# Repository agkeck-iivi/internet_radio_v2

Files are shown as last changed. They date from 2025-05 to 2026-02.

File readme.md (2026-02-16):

# Internet radio v2

## hardware

* ESP32s3 DevkitC N16R8
* ES8388 audio board
  * both clock and data lines require low pass filters with caps close to es8388
* 2 rotary encoders with push buttons and hardware debounce
  * encoder 1: volume + mute + hold down at boot to enter provisioning mode
  * encoder 2: station selection + display ip address + reboot

* 1 IR LED
* 1 OLED display spi interface

### prototype

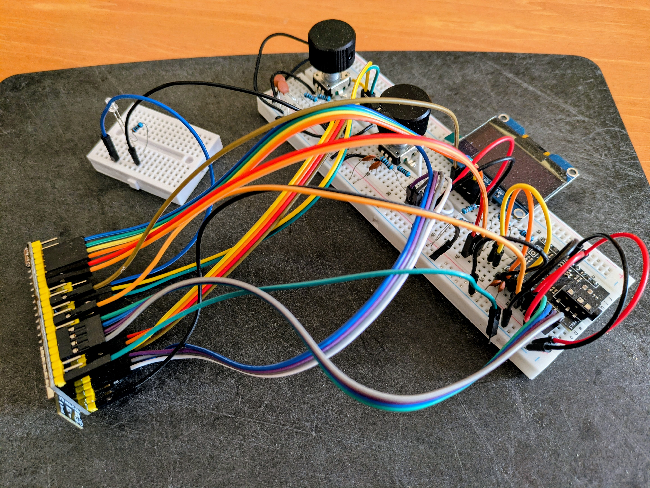
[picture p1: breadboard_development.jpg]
breadboard development

*Breadboard development*

### header wiring

header wiring
*Header wiring diagram*

### schematic

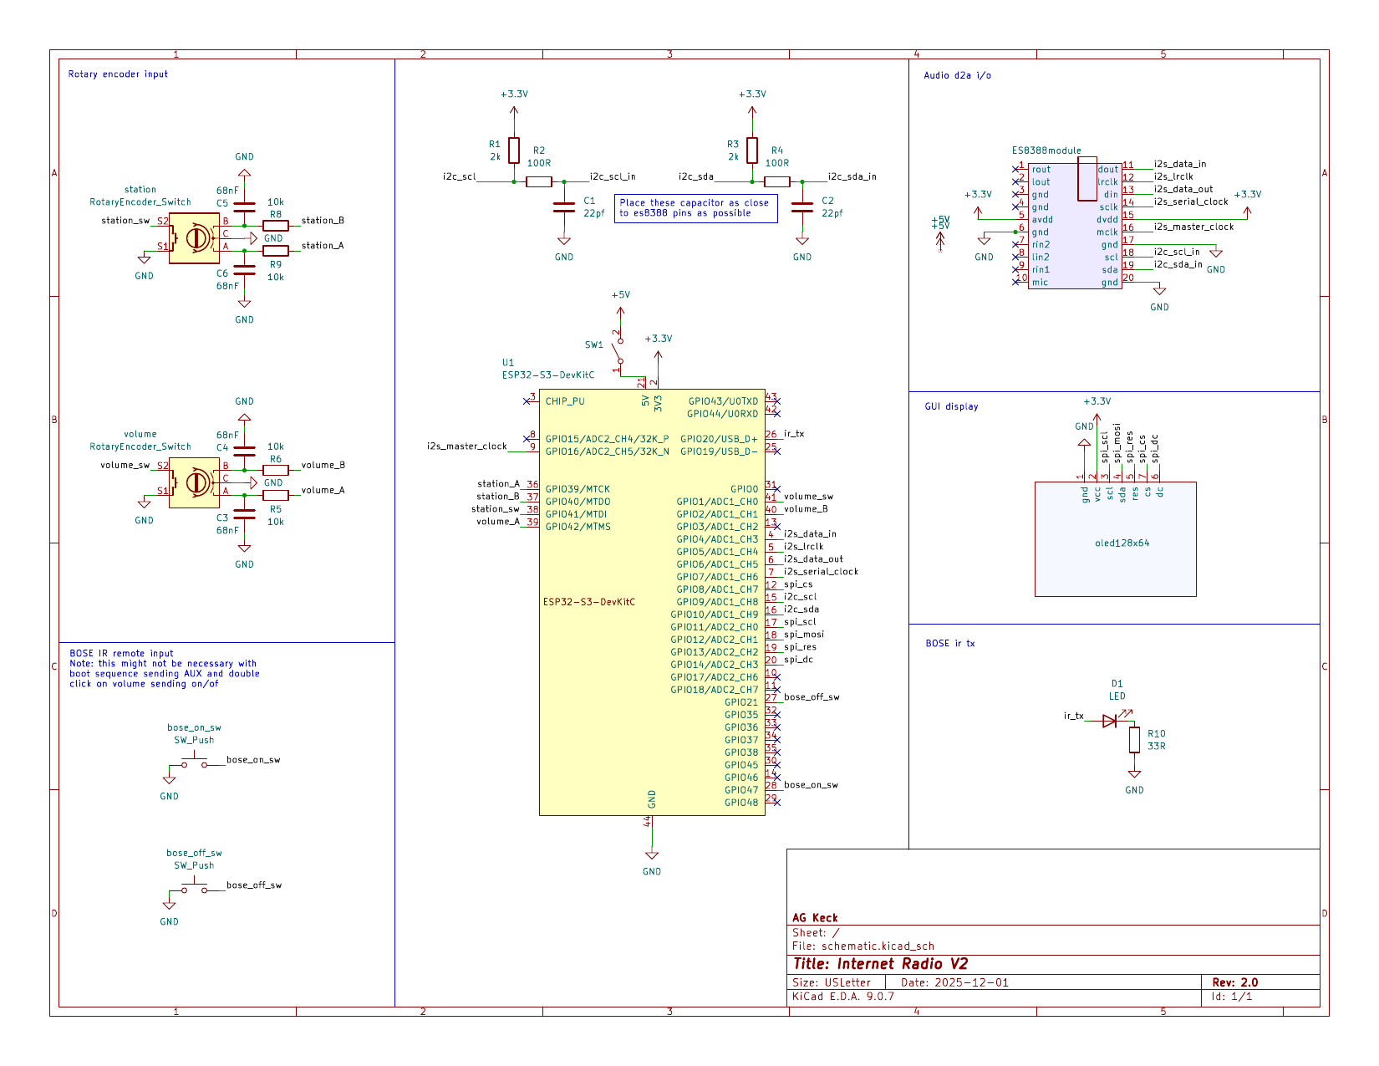
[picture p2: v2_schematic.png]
schematic

*Schematic diagram*

### build

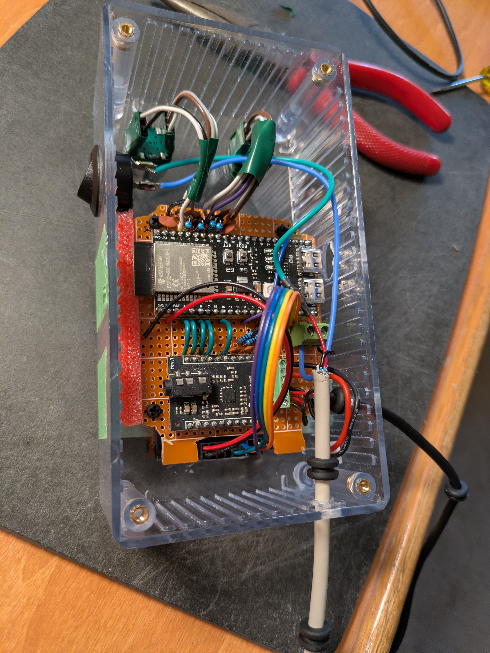
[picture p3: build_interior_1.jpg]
interior during build

*Interior during build*

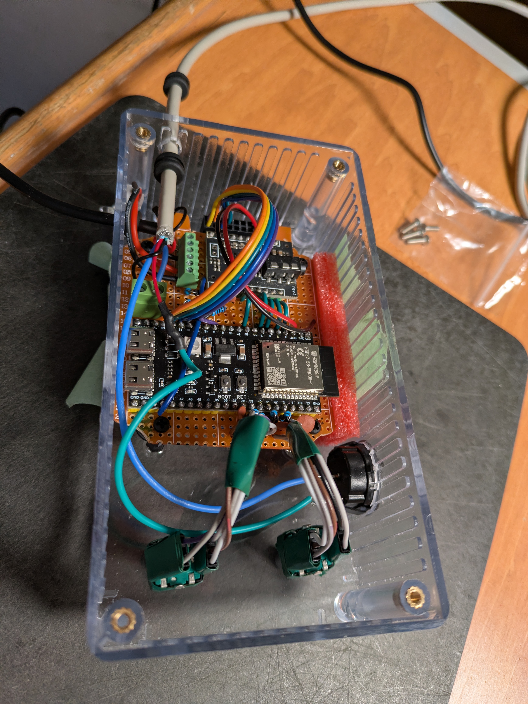
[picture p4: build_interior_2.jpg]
interior during build oblique

*Interior during build oblique*

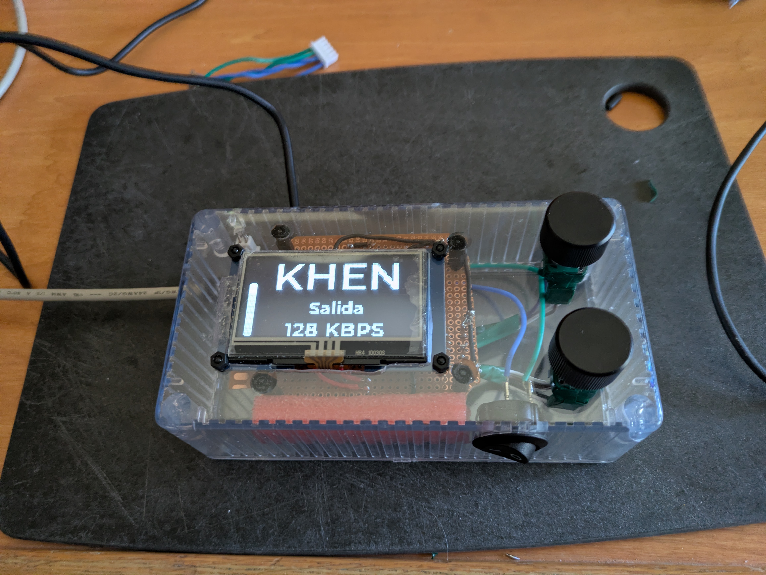
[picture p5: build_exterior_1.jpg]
front panel of completed radio

*Front panel of completed radio*

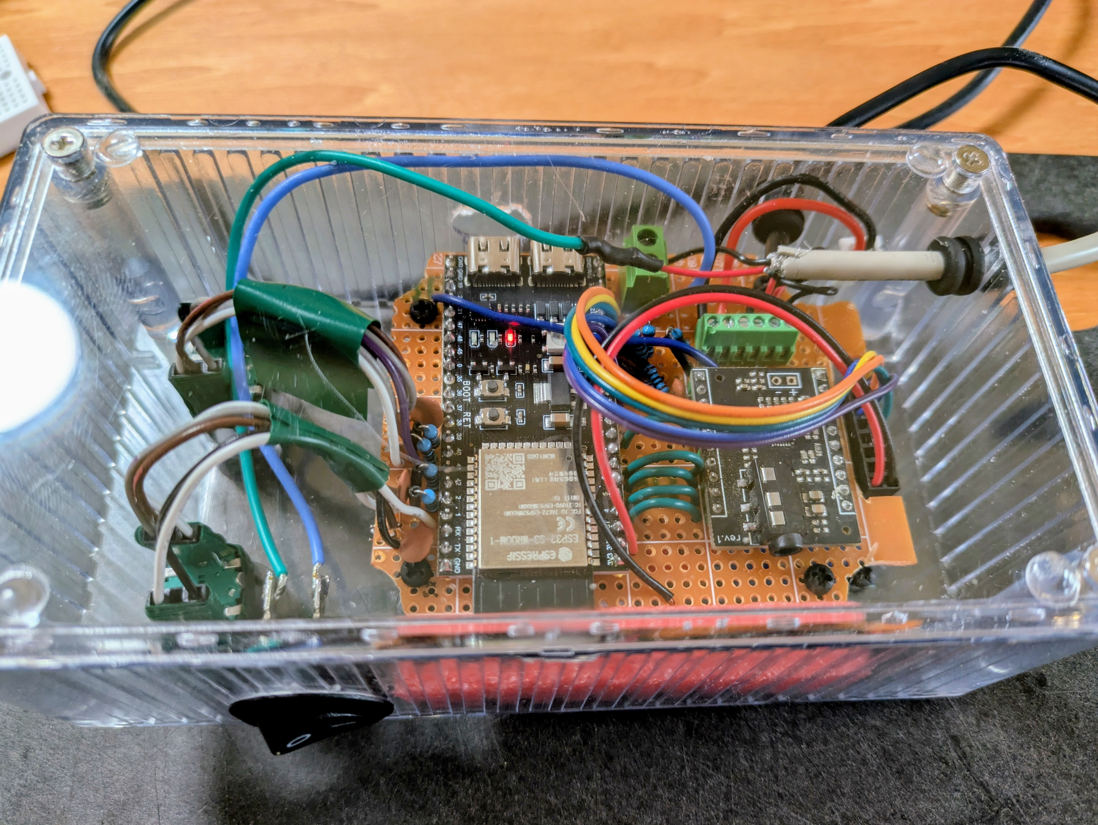
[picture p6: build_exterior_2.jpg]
back of completed radio

*Back of completed radio*

## software

### audio pipeline

The audio pipeline is virtually the same as in version 1.  We added an accumulator to count the bytes read from the http stream and a periodic task to calculate/update the bitrate display on the screen.  This task calculates a 10 second weighted average of one second bitrates.  When this weighted average is 0 we know that we have not received data for 10 seconds.  We use this signal along with a delay of 15 seconds to determine if we need to reboot the device.  If we have not received data for 10 seconds and we are at least 15 seconds since last boot we reboot the device.

### audio board

Version 1 used the LyraT sdkconfig option to identify the audio board.  In version 2 we attempt to create a custom audio board with only the necessary components.  This attempt is partially successful. We can initialize and utilize the board but there is still a lot of cruft in the custom board definition.  We will need to clean this up.

The es8388 driver that ships with esp-adf sets the gain on output 2 to -30 dB.  In order to use channel 2 I moved the driver into the es8388 board component and initialized the registers appropriately.  I think that the only linkage is through a global variable `MY_AUDIO_CODEC_ES8388_DEFAULT_HANDLE` defined in `es8388_driver.c`.  This variable contains pointers to functions that initilize and control the es8388 and is used to initialize the audio_hal.  We need to keep an eye out for other linkage since the old es8388 driver code is still in the path.

### encoders

The hardware pulse counters track the position of the encoders. This device has interupts for pulse thresholds but not for changes in pulse counts.  We use a polling task to check the pulse counts and update the encoder position.  For the volume encoder we clamp the value to the range [0, 100] and arrange the relationship between the pulse count and the [0, 100] range to saturate at the endpoints.  In this way, even if the user turns well past an endpoint the reverse movement will immediately affect the value.

### lvgl

LVGL is used for the display interface. Since LVGL is not thread-safe, we implement a **Queue-based Producer/Consumer pattern** to manage all UI updates safely.

#### Thread Safety & Queue

* **Producer**: Any task (e.g., Wi-Fi events, Encoder Logic) that wants to update the UI creates a `ui_update_message_t` struct. This struct contains an event `type` (enum) and optional `data` (int or string pointer). This message is sent to `g_ui_queue`.
* **Consumer**: The `process_ui_updates()` function runs in the main loop (or a dedicated UI task). It consumes messages from `g_ui_queue` and performs the actual LVGL API calls (e.g., `lv_label_set_text`, `lv_screen_load`). This ensures all LVGL operations happen in a single context.

#### Screens

The application uses three primary screens:

1. **Home Screen**: The main dashboard showing the Volume Slider, Station Call Sign, Origin, and Bitrate.
2. **Station Selection**: Displays a "Roller" widget allowing the user to scroll through the list of stations.
3. **Message Screen**: A generic, reusable screen with a centered label used for notifications (e.g., "Rebooting", "Provisioning", "IP Address").

#### Messaging

To display a message on the **Message Screen**:

1. **Fixed Messages**: Helper functions like `switch_to_reboot_screen()` send a message type (e.g., `SWITCH_TO_REBOOT_SCREEN`) that triggers the consumer to load the Message Screen and set a hardcoded string (e.g., "Rebooting").
2. **Arbitrary Messages**: To display dynamic text (like an IP address), the system uses the `UPDATE_IP_LABEL` message type.
    * The producer sends a message with `type = UPDATE_IP_LABEL` and `data.str_value = "My String"`.
    * The consumer reads specific string pointer and updates the label on the Message Screen.
    * *Note: Ensure the string pointer remains valid until processed, or use static/global buffers.*

### wifi

The device relies on Wi-Fi for internet connectivity. If no Wi-Fi credentials are provided (e.g., typically on the first boot), the device enters **Provisioning Mode**.

**Provisioning Mode**:

* The device broadcasts a Bluetooth LE (BLE) service.
* Use the **Espressif BLE Provisioning** app (available on iOS and Android) to connect to the device.
* Follow the app instructions to scan for Wi-Fi networks and provide the SSID and password.
* Once credentials are received, the device will connect to the Wi-Fi network and save the credentials to NVS for future boots.
* **Forced Reprovisioning**: To reset the Wi-Fi credentials and force the device back into provisioning mode, **press and hold the Volume Encoder button** while powering on (or rebooting) the device.

### ir

The Bose Wave radio uses an IR remote control for all functions. Version 2 is designed for this particular unit so we generate our own IR signals to control the radio.  After sniffing the IR signals with ir_nec_transciever project we see that the radio does not use the NEC protocal.  Using 10 samples of the on/off button and 10 samples of the aux button we create a concensus signal for each message. The colab: `bose_sig_analysis.ipynb` shows the analysis of the IR signals.

The bose IR protocal is stateful: the on/off button performs different functions based on the state of the radio.  The aux button is stateless, this signal will always result in the radio being on with input from the aux jack.  Therefore we use aux as the on signal and aux + on/off as the off signal.  We send aux during the boot sequence to ensure that the radio is on when we boot.  We expect the user to double click the volume encoder to turn the radio off.

### nvs

### station data

Initial station data is stored in a constant array.  On first boot, if the spiffs is not initialized we create a default station json file based on the constant array.  Thereafter, on boot the spiffs should be found and the json file serves as the source of truth for station data.  We provide an API to load the station data from the json file and save the station data to the json file.

To download the current stations:

```{bash}
curl http://<ESP32_IP_ADDRESS>/api/stations -o stations.json
```

To update the stations:

```{bash}
curl -X POST -H "Content-Type: application/json" -d @stations.json http://<ESP32_IP_ADDRESS>/api/stations
```

where the codec enum uses these values:
0: MP3
1: AAC
2: OGG
3: FLAC

For help finding stream URIs and codecs for your favorite stations, see the [Station Discovery Guide](station_discovery.md).

### web update to station data

We provide a web interface to update the station data at <ESP32_IP_ADDRESS>/api/stations (or just <ESP_IP_ADDRESS> where there is a link to station data.)  From the web interface we can add, remove, and update station data as well a reorder the list of stations.  The station data is saved to the spiffs and a reboot will apply the changes.

## operation

The radio's user interface is driven by two rotary encoders, each equipped with an integrated push button (switch).

### Control Summary Table

| Control | Action | Function |
| :--- | :--- | :--- |
| **Volume Encoder** | Rotation | Adjust volume (0-100); Auto-unmutes if turned |
| | Single Click | Toggle Mute/Unmute |
| | Double Click | Send **Bose ON/OFF** IR command |
| | **Hold at Boot** | **Force Reprovisioning** (Wipe Wi-Fi credentials) |
| **Station Encoder** | Rotation | Scroll through stations; Selects after 2s inactivity |
| | Short Press | Display **IP Address** (3 seconds) |
| | Long Press (>1.5s) | **Reboot** device |

---

### Detailed Usage

#### Volume Encoder (Left)

* **Rotation**: Sets the volume level between 0 and 100.
  * The volume is saved to NVS and persists across reboots.
  * If the device is muted, any rotation will automatically restore the previous volume plus or minus the rotation delta.
* **Single Click**: Toggles the mute state. Muting sets output to 0 while remembering the previous level for restoration.
* **Double Click**: Triggers the IR transmitter to send a power toggle command to the connected Bose system.
* **Boot Action**: Holding this button during power-on or reset will trigger `wifi_prov_mgr_reset_provisioning()`, allowing you to connect a new Wi-Fi network via BLE.

#### Station Encoder (Right)

* **Rotation**: Navigates the station list.
  * Turning the knob switches the display to the **Station Selection** screen.
  * **Auto-Selection**: Once you stop turning, the radio waits for **2 seconds** before committing the change, switching the stream, and returning to the Home screen.
* **Short Press**: Briefly switches the screen to show the current IP address. This is useful for accessing the web configuration interface.
* **Long Press**: Holding for more than 1.5 seconds triggers an immediate system reboot. A "Rebooting" message will appear on the display as confirmation.

## Bugs

* 5v power does not work perfectly. On first power on after a period off,
the system will not boot. If the 5v power is cycled once, it will work fine.
  * A 10 uF decoupling capacitor was added across the 5v header but that didn't solve the issue.
  * A 470 uF capacitor was added across the 5v header but that didn't solve the issue.
  * A 10 uF capacitor was added to rst pin to ground but that didn't solve the issue.
  * A 470 uF capacitor was added to rst pin to ground but that didn't solve the issue.

  * **Solved** by adding a 10K pullup resistor from GPIO 0 to 3.3v.  This causes the radio to reliably boot into stored application when running on external 5v supply.

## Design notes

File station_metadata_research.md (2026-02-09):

# Station Metadata Research Report (Rev 3)

This report outlines the verified strategies for implementing "Now Playing" displays, incorporating user feedback and final validation.

## Executive Summary

We have moved away from the assumption of a single metadata standard. The 16 stations will be handled by three distinct "Metadata Drivers":

1. **KEXP Driver**: Uses the verified KEXP V2 JSON API.
2. **Spinitron Driver**: Scrapes public Spinitron pages. This is the **primary solution** for 6+ stations (KXLU, KSUT, KOTO, KDUR, KBUT, WMBR) that lack direct stream metadata.
3. **Standard Driver**: Uses `status-json.xsl` or in-stream ICY metadata for the remaining stations.

## Detailed Station Analysis

### 1. KEXP (Custom API)

* **Status**: **VERIFIED**
* **Endpoint**: `https://api.kexp.org/v2/plays/?format=json&limit=1`
* **Format**: JSON. High reliability.

### 2. Spinitron Stations

These stations rely on Spinitron for playlist management. We will scrape their public "current song" display.

* **Status**: **VERIFIED** (for most)
* **Target Pattern**: `https://spinitron.com/[STATION_NAME]/`
* **Parsing**: Find `data-current-song` attribute or `.current-song` class in HTML.

| Station | Verified URL | Notes |
| :--- | :--- | :--- |
| **KXLU** | `https://spinitron.com/KXLU/` | Confirmed reachable. |
| **KDUR** | `https://spinitron.com/KDUR/` | Confirmed by user. |
| **KOTO** | `https://spinitron.com/KOTO/` | Confirmed by user. |
| **KBUT** | `https://spinitron.com/KBUT/` | Confirmed reachable. |
| **WMBR** | `https://spinitron.com/WMBR/` | Confirmed reachable. |
| **KALX** | `https://spinitron.com/KALX/` | Confirmed reachable. |
| **WPRB** | `https://spinitron.com/WPRB/` | Confirmed reachable. |
| **KFFP** | `https://spinitron.com/KFFP/` | Confirmed reachable. |
| **KBOO** | `https://spinitron.com/KBOO/` | Confirmed reachable. |
| **KRCL** | `https://spinitron.com/KRCL/` | Confirmed reachable. |
| **KSUT** | `https://spinitron.com/ksutfourcorners/` | Confirmed reachable (via user suggestion). |

### 3. StreamTheWorld & Generic

* **StreamTheWorld**: KBUT and KOTO are now handled by **Spinitron** (see above). KUFM likely follows this pattern or uses the standard driver.
* **Generic Stations** (WFUV, KHEN, KWSB): **Standard Driver (ICY Metadata)**.
  * *Research Note*: Scraping of homepages (`wfuv.org`, `khen.org`, `kwsb.org`) for Spinitron links yielded negative results.
  * **Strategy**: Attempt `status-json.xsl`. If unavailable, use in-stream ICY metadata (native ESP-ADF feature).

## Implementation Plan

### 1. Data Structures

Update `station_config_t` to support the driver model:

```c
typedef enum {
    META_DRIVER_ICECAST_JSON,   // Default
    META_DRIVER_KEXP_V2,        // Custom
    META_DRIVER_SPINITRON,      // Scraper
} metadata_driver_t;

typedef struct {
    // ...
    metadata_driver_t meta_driver;
    char *meta_uri; // e.g. "https://spinitron.com/KXLU/"
} station_config_t;
```

### 2. Spinitron Scraper Logic

Since Spinitron pages are HTML, we need a lightweight scraper:

* HTTP GET the `meta_uri`.
* Search for specific tokens: `<tr class="current-song">` or `data-current-song="`.
* Extract text between tags.
* *Optimization*: Use `Range` headers to fetch only the first ~15KB of the page if the metadata is near the top.

### 3. Next Steps

1. Implement the **KEXP Driver** (Easiest, high value).
2. Implement the **Spinitron Driver** (Unlocks 6+ stations).
3. Refine **KSUT** handling during the Spinitron implementation phase.

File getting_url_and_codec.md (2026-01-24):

# How to find url/codec for  radio streams, current song, and bitrate

## Identifying url

<https://fmstream.org> or ask gemini

## Identifying codec

```{bash}
ffprobe -v error -select_streams a:0 -show_entries stream=codec_name -of default=noprint_wrappers=1:nokey=1 <url>
```

## Measuring bitrate

```{bash}
ffprobe -v error -select_streams a:0 -show_entries stream=bit_rate -of default=noprint_wrappers=1:nokey=1 <url>
```

## getting currently playing song

### kexp

```{bash}
curl -s "https://api.kexp.org/v2/plays/?limit=1" | jq '.results[0] | {artist, song, album}'
```

## Station Bitrate Reference

The following table shows the measured bitrates for the default radio stations (calculated using `ffprobe`).

| Call Sign | Measured Bitrate | URI |
| :--- | :--- | :--- |
| KEXP | 160 kbps | `https://kexp.streamguys1.com/kexp160.aac` |
| KBUT | 64 kbps | `http://playerservices.streamtheworld.com/api/livestream-redirect/KBUTFM.mp3` |
| KSUT | 64 kbps | `https://ksut.streamguys1.com/kute` |
| KDUR | 128 kbps | `https://kdurradio.fortlewis.edu/stream` |
| KOTO | 128 kbps | `http://26193.live.streamtheworld.com/KOTOFM.mp3` |
| KHEN | 128 kbps | `https://stream.pacificaservice.org:9000/khen_128` |
| KWSB | 128 kbps | `https://kwsb.streamguys1.com/live` |
| KFFP | 256 kbps | `http://listen.freeformportland.org:8000/stream` |
| KBOO | 192 kbps | `https://live.kboo.fm:8443/high` |
| KXLU | 48 kbps | `http://kxlu.streamguys1.com:80/kxlu-lo` |
| WPRB | 96 kbps | `https://wprb.streamguys1.com/listen.mp3` |
| WMBR | 128 kbps | `https://wmbr.org:8002/hi` |
| KALX | 128 kbps | `https://stream.kalx.berkeley.edu:8443/kalx-128.mp3` |
| WFUV | 128 kbps | `https://onair.wfuv.org/onair-hi` |
| KUFM | 64 kbps | `https://playerservices.streamtheworld.com/api/livestream-redirect/KUFMFM.mp3` |
| KRCL | 256 kbps | `http://stream.xmission.com:8000/krcl-low` |

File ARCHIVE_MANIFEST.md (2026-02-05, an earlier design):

# Archive Manifest: Internet Radio v2 (ESP32-S3)

This project has been prepared for long-term archival. To ensure the code remains buildable, critical components have been vendored and patched to maintain compatibility with modern ESP-IDF versions.

## Build Environment

| Requirement | Version | Path |
| :--- | :--- | :--- |
| **ESP-IDF** | v5.5.1 | `/home/agkeck/esp/v5.5.1/esp-idf` |
| **ESP-ADF** | v2.7 (Release) | `/home/agkeck/esp/esp-idf/tools/esp-adf` |
| **Toolchain** | xtensa-esp-elf-14.2.0 | Standard IDF v5.5.1 Tools |
| **Target Chip** | ESP32-S3 | |

## Critical Modifications for Archival

### Vendored Components

The following components were moved from the global ADF directory into the project's `components/` directory to ensure they are captured in the project's source control/archive:

1. **esp_peripherals**: Vendored from `$ADF_PATH/components/esp_peripherals`.

### Compatibility Patches

To resolve a "fatal error: esp32/rom/crc.h: No such file or directory" issue caused by IDF v5.x removal of legacy headers on the S3 target:

* **File**: `components/esp_peripherals/lib/blufi/blufi_security.c`
* **Change**:
  * Replaced `#include "esp32/rom/crc.h"` with `#include "esp_rom_crc.h"`.
  * Replaced call to `crc16_be()` with `esp_rom_crc16_be()`.

## Verification Status

- [x] **Configuration**: Project configured for ESP32-S3.
* [x] **Compilation**: `idf.py build` completed successfully using the vendored components.
* [x] **Artifact Presence**: `build/internet_radio_v2.bin` generated.

## Recovery Notes

If this project needs to be built on a new system:

1. Install ESP-IDF v5.5.1 and its tools.
2. Install ESP-ADF v2.7.
3. Set `ADF_PATH` environment variable.
4. Run `idf.py build`. The project-local `esp_peripherals` will automatically override the version in the ADF directory.

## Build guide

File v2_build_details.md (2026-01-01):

# Version 2 build details
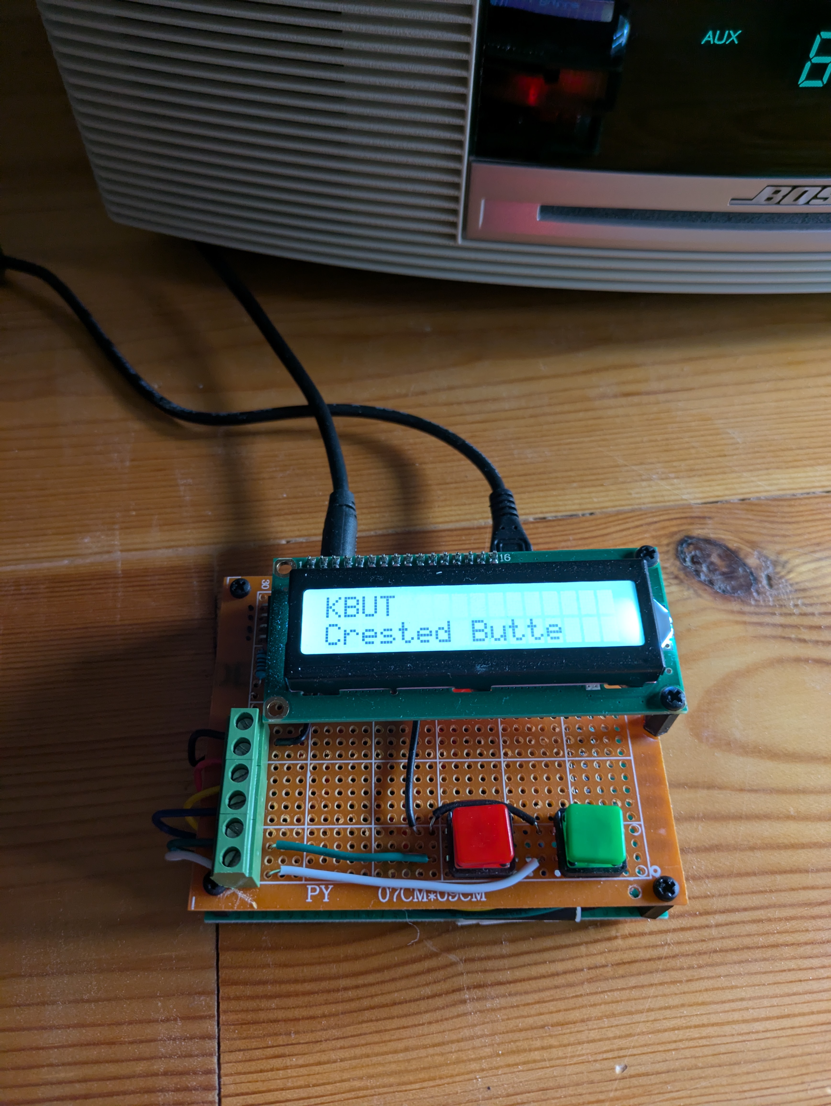
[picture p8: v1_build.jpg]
internet radio version 1 build

## hardware
* ESP32s3 DevkitC N16R8
* ES8388 audio board
  * both clock and data lines require low pass filters with caps close to es8388
* 2 rotary encoders with push buttons and hardware debounce
  * encoder 1: volume + mute
  * encoder 2: station selection + display ip address + reboot

* 1 IR LED
* 1 OLED? display spi interface
### prototype
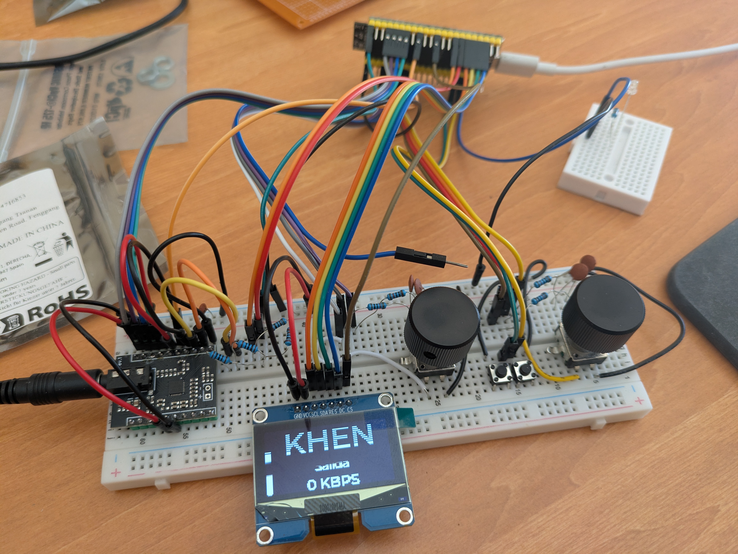
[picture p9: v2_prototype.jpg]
internet radio version 2 prototype

### schematic
internet radio version 2 schematic 

## software

### audio pipeline
The audio pipeline is virtually the same as in version 1.  We added an accumulator to count the bytes read from the http stream and a periodic task to calculate/update the bitrate display on the screen.  This task calculates a 10 second weighted average of one second bitrates.  When this weighted average is 0 we know that we have not received data for 10 seconds.  We use this signal along with a delay of 15 seconds to determine if we need to reboot the device.  If we have not received data for 10 seconds and we are at least 15 seconds since last boot we reboot the device.
### audio board
Version 1 used the LyraT sdkconfig option to identify the audio board.  In version 2 we attempt to create a custom audio board with only the necessary components.  This attempt is partially successful. We can initialize and utilize the board but there is still a lot of cruft in the custom board definition.  We will need to clean this up.

The es8388 driver that ships with esp-adf sets the gain on output 2 to -30 dB.  In order to use channel 2 I moved the driver into the es8388 board component and initialized the registers appropriately.  I think that the only linkage is through a global variable `MY_AUDIO_CODEC_ES8388_DEFAULT_HANDLE` defined in `es8388_driver.c`.  This variable contains pointers to functions that initilize and control the es8388 and is used to initialize the audio_hal.  We need to keep an eye out for other linkage since the old es8388 driver code is still in the path.
### encoders
The hardware pulse counters track the position of the encoders. This device has interupts for pulse thresholds but not for changes in pulse counts.  We use a polling task to check the pulse counts and update the encoder position.  For the volume encoder we clamp the value to the range [0, 100] and arrange the relationship between the pulse count and the [0, 100] range to saturate at the endpoints.  In this way, even if the user turns well past an endpoint the reverse movement will immediately affect the value.
### lvgl
LVGL is used for the display interface. Since LVGL is not thread-safe, we implement a **Queue-based Producer/Consumer pattern** to manage all UI updates safely.

#### Thread Safety & Queue
*   **Producer**: Any task (e.g., Wi-Fi events, Encoder Logic) that wants to update the UI creates a `ui_update_message_t` struct. This struct contains an event `type` (enum) and optional `data` (int or string pointer). This message is sent to `g_ui_queue`.
*   **Consumer**: The `process_ui_updates()` function runs in the main loop (or a dedicated UI task). It consumes messages from `g_ui_queue` and performs the actual LVGL API calls (e.g., `lv_label_set_text`, `lv_screen_load`). This ensures all LVGL operations happen in a single context.

#### Screens
The application uses three primary screens:
1.  **Home Screen**: The main dashboard showing the Volume Slider, Station Call Sign, Origin, and Bitrate.
2.  **Station Selection**: Displays a "Roller" widget allowing the user to scroll through the list of stations.
3.  **Message Screen**: A generic, reusable screen with a centered label used for notifications (e.g., "Rebooting", "Provisioning", "IP Address").

#### Messaging
To display a message on the **Message Screen**:
1.  **Fixed Messages**: Helper functions like `switch_to_reboot_screen()` send a message type (e.g., `SWITCH_TO_REBOOT_SCREEN`) that triggers the consumer to load the Message Screen and set a hardcoded string (e.g., "Rebooting").
2.  **Arbitrary Messages**: To display dynamic text (like an IP address), the system uses the `UPDATE_IP_LABEL` message type.
    *   The producer sends a message with `type = UPDATE_IP_LABEL` and `data.str_value = "My String"`.
    *   The consumer reads specific string pointer and updates the label on the Message Screen.
    *   *Note: Ensure the string pointer remains valid until processed, or use static/global buffers.*

### wifi
The device relies on Wi-Fi for internet connectivity. If no Wi-Fi credentials are provided (e.g., typically on the first boot), the device enters **Provisioning Mode**.

**Provisioning Mode**:
*   The device broadcasts a Bluetooth LE (BLE) service.
*   Use the **Espressif BLE Provisioning** app (available on iOS and Android) to connect to the device.
*   Follow the app instructions to scan for Wi-Fi networks and provide the SSID and password.
*   Once credentials are received, the device will connect to the Wi-Fi network and save the credentials to NVS for future boots.
*   **Forced Reprovisioning**: To reset the Wi-Fi credentials and force the device back into provisioning mode, **press and hold the Volume Encoder button** while powering on (or rebooting) the device.

### ir
The Bose Wave radio uses an IR remote control for all functions. Version 2 is designed for this particular unit so we generate our own IR signals to control the radio.  After sniffing the IR signals with ir_nec_transciever project we see that the radio does not use the NEC protocal.  Using 10 samples of the on/off button and 10 samples of the aux button we create a concensus signal for each message. The colab: `bose_sig_analysis.ipynb` shows the analysis of the IR signals.

The bose IR protocal is stateful: the on/off button performs different functions based on the state of the radio.  The aux button is stateless, this signal will always result in the radio being on with input from the aux jack.  Therefore we use aux as the on signal and aux + on/off as the off signal.  We send aux during the boot sequence to ensure that the radio is on when we boot.  We expect the user to double click the volume encoder to turn the radio off.
### nvs
### station data
Initial station data is stored in a constant array.  On first boot, if the spiffs is not initialized we create a default station json file based on the constant array.  Thereafter, on boot the spiffs should be found and the json file serves as the source of truth for station data.  We provide an API to load the station data from the json file and save the station data to the json file.

```{bash}
curl -X POST -H "Content-Type: application/json" -d '[{"call_sign":"TestRadio","origin":"Home","uri":"http://test.com","codec":1}]' http://<ESP32_IP_ADDRESS>/api/stations
```
where the codec enum uses these values:
0: MP3
1: AAC
2: OGG
3: FLAC

### web update to station data
We provide a web interface to update the station data at <ESP32_IP_ADDRESS>/api/stations (or just <ESP_IP_ADDRESS> where there is a link to station data.)  From the web interface we can add, remove, and update station data as well a reorder the list of stations.  The station data is saved to the spiffs and a reboot will apply the changes.

## construction
Phase 1: Solder the esp32 and es8388 boards with low pass filters and pullup resistors for I2C bus to build the audio pipeline.  Connectors for the jumpers to controls, display, ir, audio, and power are shown but not yet finalized.
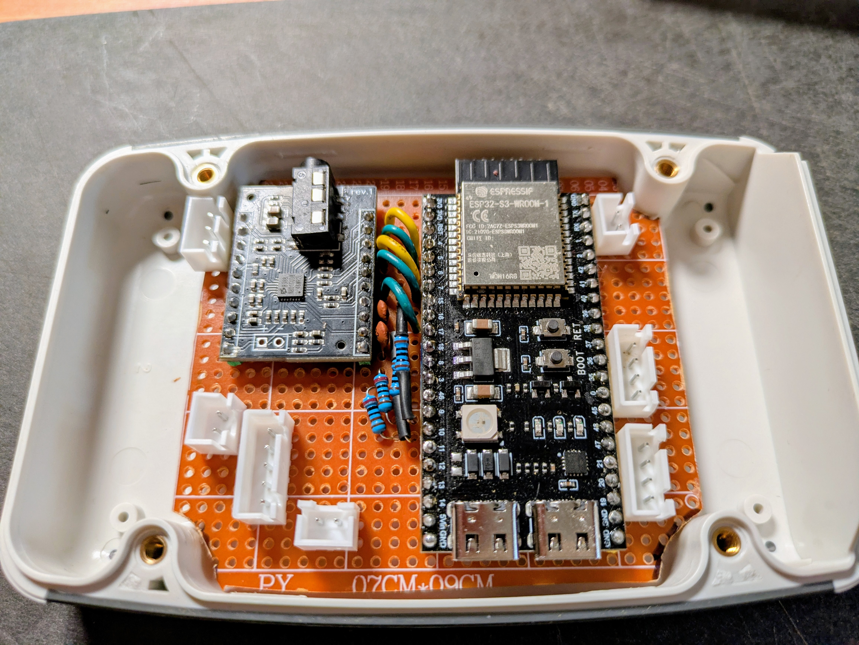
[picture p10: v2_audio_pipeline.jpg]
internet radio version 2 construction phase 1


## operation

The radio manages its user interface primarily through two rotary encoders, each with an integrated push button.

### Volume Encoder
*   **Rotation**: Adjusts the volume between 0 and 100.
    *   Changes are reflected immediately on the OLED volume slider.
    *   The volume level is saved to NVS and persists across reboots.
    *   Rotating the knob while muted will automatically unmute the device.
*   **Button Press (Single Click)**: Toggles **Mute**.
    *   Muting sets the volume to 0.
    *   Unmuting restores the volume to the previous level.
*   **Button Press (Double Click)**: Sends a **Bose ON/OFF** IR command (via the IR transmitter).

### Station Encoder
*   **Rotation**: detailed station selection.
    *   Turning the knob switches the display to the "Station Selection" screen.
    *   You can scroll through the available stations (wrapping around the list).
    *   **Selection**: Stop turning the knob to select a station. After **2 seconds** of inactivity, the radio will:
        1.  Switch to the selected station.
        2.  Begin streaming.
        3.  Return to the Home screen.
*   **Button Press (Short)**: Displays the device's **IP Address** on the screen for 5 seconds, then returns to Home.
*   **Button Press (Long > 1.5s)**: **Reboots** the device. A reboot message is displayed before the system restarts.
*   **Hold During Boot**: Forces **Reprovisioning**.
    *   If the volume button is held down while the device powers on, it will erase current Wi-Fi credentials and return to provisioning mode.

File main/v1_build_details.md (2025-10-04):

# Version 1 build details
internet radio version 1 build
## hardware
* ESP32 DevkitC N8R8
* ES8388 audio board
* LCD1602 display (i2c interface)
* 2 buttons
* usb cable with on/off switch
## software
* espressif_button component
* zorxx__lcd1602 component
* mp3 and aac streams confirmed.  flac is implemented but not currently working
* current station selection stored in NVS
* wifi and station configuration compiled in code.

## construction
* bottom board
  * esp32 devkit
  * es8388 audio board
  * 4 pullup resistors for two i2c buses.  One i2c bus supports es8388 communication and the other supports lcd1602 communication.
  * I did not build out the low pass filter for the es8388 i2c.  Initialization works (perhaps because the i2s bus hasn't started yet) but further i2c communication is lost.  In a future version I'll build the low pass filter on this bus.
* top board
  * use 3x2pin screw header to lead lines from bottom board to top board
    * reading from lcd 1602 side: gnd, vcc, sda, scl, station down, station up
  * mount 4 pin 90 deg. connector to attach to lcd 1602
  * low pass filters for sda and scl on top board on the far side of the lcd 1602 connector
  * cut hole in top board for lcd 1602 contrast trip pot.
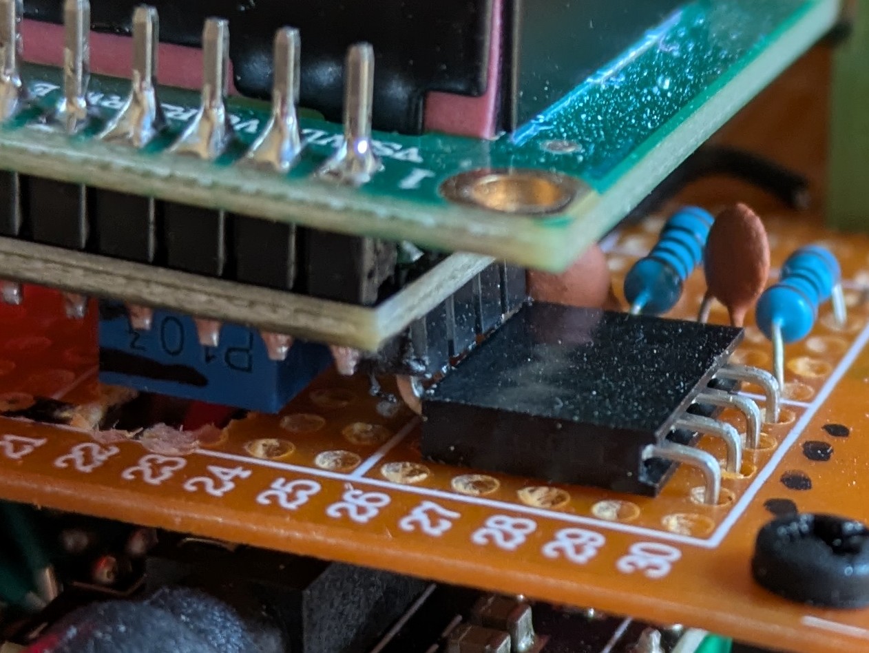
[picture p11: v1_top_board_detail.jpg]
internet radio version 1 top board detail


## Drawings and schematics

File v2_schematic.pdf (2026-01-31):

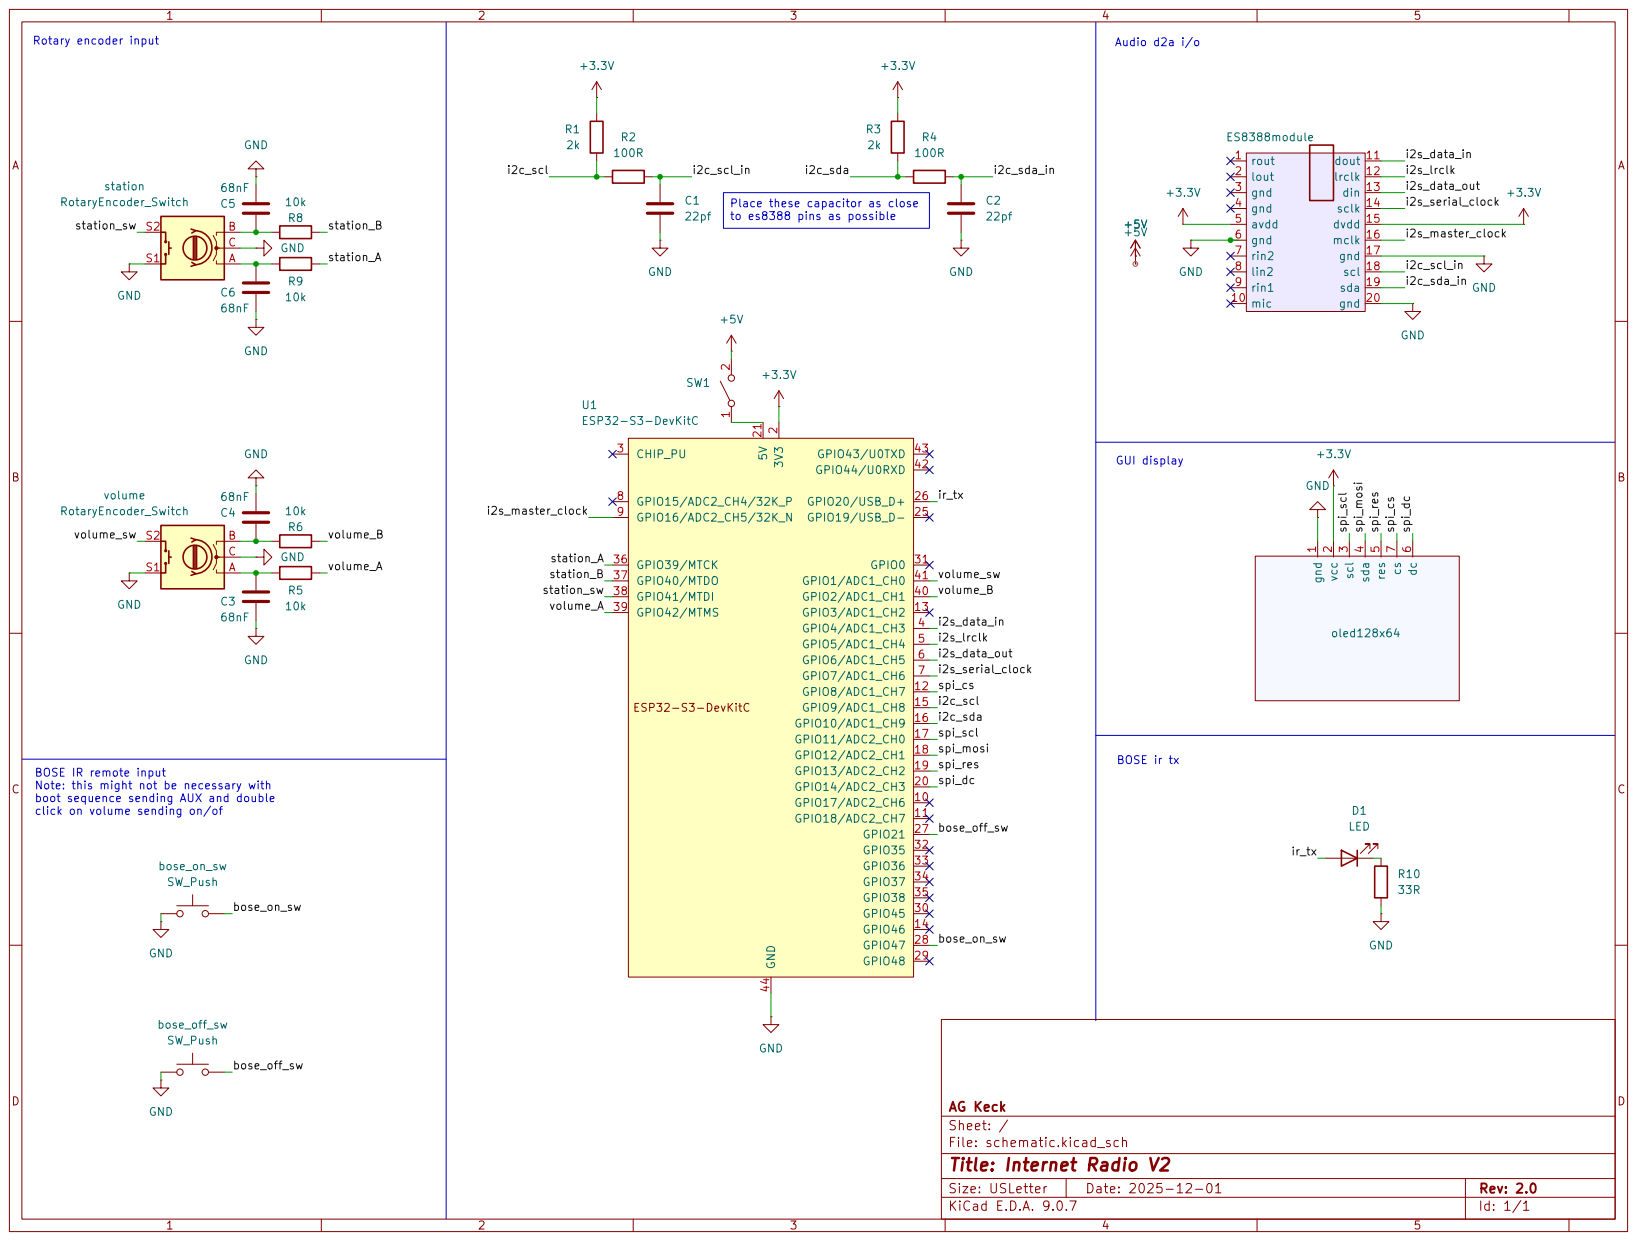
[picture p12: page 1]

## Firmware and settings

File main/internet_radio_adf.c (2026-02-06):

/* Play internet radio stations

    based on esp-adf code: pipeline_living_stream

   This example code is in the Public Domain (or CC0 licensed, at your option.)

   Unless required by applicable law or agreed to in writing, this
   software is distributed on an "AS IS" BASIS, WITHOUT WARRANTIES OR
   CONDITIONS OF ANY KIND, either express or implied.
*/

#include "audio_common.h"
#include "audio_event_iface.h"
#include "audio_pipeline_manager.h"
#include "board.h"
// #include "driver/gpio.h"
#include "encoders.h"
#include "esp_event.h"
#include "esp_heap_caps.h"
#include "esp_log.h"
#include "esp_netif.h"
#include "esp_peripherals.h"
#include "esp_wifi.h"
// #include "freertos/FreeRTOS.h"
#include "freertos/event_groups.h"
#include "freertos/task.h"
#include "ir_rmt.h"
#include "lvgl_ssd1306_setup.h"
#include "nvs_flash.h"
#include "screens.h"
// #include "sdkconfig.h"
#include "station_data.h"
#include "web_server.h"
#include "wifi_provisioning/manager.h"
#include "wifi_provisioning/scheme_ble.h"
#include <string.h>

static const char *TAG = "INTERNET_RADIO";

// Volume control
#define INITIAL_VOLUME 0

#define IR_TX_GPIO_NUM 20

#define BUTTON_POLLING_PERIOD_MS 100

#define BITRATE_UPDATE_INTERVAL_MS 1000

// oled screen with lvgl
extern int station_count; // from station_data.c
static lv_display_t *display;

// global variables for easier access in callbacks
audio_pipeline_components_t audio_pipeline_components = {0};
int current_station = 0;

static audio_board_handle_t board_handle =
    NULL; // make this global during debugging
static audio_event_iface_handle_t evt = NULL;
static esp_periph_set_handle_t periph_set = NULL;
rmt_channel_handle_t g_ir_tx_channel = NULL;

volatile int g_bitrate_kbps = 0;
// system monitor logging enable
static bool g_enable_sys_monitor = true;
// Button Handles
static EventGroupHandle_t wifi_event_group;
const int WIFI_CONNECTED_BIT = BIT0;

static void save_current_station_to_nvs(int station_index) {
  nvs_handle_t nvs_handle;
  esp_err_t err = nvs_open("storage", NVS_READWRITE, &nvs_handle);
  if (err != ESP_OK) {
    ESP_LOGE(TAG, "Error (%s) opening NVS handle for writing!",
             esp_err_to_name(err));
    return;
  }

  err = nvs_set_i32(nvs_handle, "station_idx", station_index);
  if (err != ESP_OK) {
    ESP_LOGE(TAG, "Error (%s) writing 'station_idx' to NVS!",
             esp_err_to_name(err));
  } else {
    ESP_LOGI(TAG, "Saved current_station = %d to NVS", station_index);
  }

  err = nvs_commit(nvs_handle);
  if (err != ESP_OK) {
    ESP_LOGE(TAG, "Error (%s) committing 'station_idx' to NVS!",
             esp_err_to_name(err));
  }

  nvs_close(nvs_handle);
}

void change_station(int new_station_index) {
  esp_err_t ret;

  if (new_station_index < 0 || new_station_index >= station_count) {
    ESP_LOGE(TAG, "Invalid station index: %d", new_station_index);
    return;
  }

  // Only change if the new station is different from the current one
  if (new_station_index == current_station) {
    ESP_LOGI(TAG, "Station %d is already selected. No change needed.",
             new_station_index);
    return;
  }

  ESP_LOGI(TAG, "Destroying current pipeline...");
  destroy_audio_pipeline(&audio_pipeline_components);

  current_station = new_station_index;
  ESP_LOGI(TAG, "Switching to station %d: %s, %s", current_station,
           radio_stations[current_station].call_sign,
           radio_stations[current_station].origin);
  sync_station_encoder_index(); // Sync encoder's internal state
  save_current_station_to_nvs(current_station);
  update_station_name(radio_stations[current_station].call_sign);
  update_station_origin(radio_stations[current_station].origin);

  ret = create_audio_pipeline(&audio_pipeline_components,
                              radio_stations[current_station].codec,
                              radio_stations[current_station].uri);
  if (ret != ESP_OK) {
    ESP_LOGE(
        TAG,
        "Failed to create new audio pipeline for station %s, %s. Error: %d",
        radio_stations[current_station].call_sign,
        radio_stations[current_station].origin, ret);
    return;
  }

  ESP_LOGI(TAG, "Starting new audio pipeline");
  ret = audio_pipeline_run(audio_pipeline_components.pipeline);
  if (ret != ESP_OK) {
    ESP_LOGE(TAG, "Failed to run new audio pipeline. Error: %d", ret);
    destroy_audio_pipeline(&audio_pipeline_components);
  }
}

/* Event handler for catching system events */
static void event_handler(void *arg, esp_event_base_t event_base,
                          int32_t event_id, void *event_data) {
  if (event_base == WIFI_PROV_EVENT) {
    switch (event_id) {
    case WIFI_PROV_START:
      switch_to_provisioning_screen();
      ESP_LOGI(TAG, "Provisioning started");
      break;
    case WIFI_PROV_CRED_RECV: {
      wifi_sta_config_t *wifi_sta_cfg = (wifi_sta_config_t *)event_data;
      ESP_LOGI(TAG,
               "Received Wi-Fi credentials"
               "\n\tSSID: %s\n\tPassword: %s",
               (const char *)wifi_sta_cfg->ssid,
               (const char *)wifi_sta_cfg->password);
      break;
    }
    case WIFI_PROV_CRED_FAIL: {
      wifi_prov_sta_fail_reason_t *reason =
          (wifi_prov_sta_fail_reason_t *)event_data;
      ESP_LOGE(TAG,
               "Provisioning failed!\n\tReason: %s"
               "\n\tPlease reset to factory and retry.",
               (*reason == WIFI_PROV_STA_AUTH_ERROR)
                   ? "Wi-Fi station authentication failed"
                   : "Wi-Fi station not found");
      break;
    }
    case WIFI_PROV_CRED_SUCCESS:
      switch_to_home_screen();
      ESP_LOGI(TAG, "Provisioning successful");
      break;
    case WIFI_PROV_END:
      /* De-initialize manager once provisioning is finished */
      wifi_prov_mgr_deinit();
      break;
    default:
      break;
    }
  } else if (event_base == WIFI_EVENT && event_id == WIFI_EVENT_STA_START) {
    esp_wifi_connect();
  } else if (event_base == IP_EVENT && event_id == IP_EVENT_STA_GOT_IP) {
    ip_event_got_ip_t *event = (ip_event_got_ip_t *)event_data;
    ESP_LOGI(TAG, "Got IP: " IPSTR, IP2STR(&event->ip_info.ip));
    xEventGroupSetBits(wifi_event_group, WIFI_CONNECTED_BIT);
  } else if (event_base == WIFI_EVENT &&
             event_id == WIFI_EVENT_STA_DISCONNECTED) {
    ESP_LOGI(TAG, "Disconnected. Connecting to the AP again...");
    esp_wifi_connect();
  }
}

static void wifi_init_sta(void) {
  /* Start Wi-Fi in station mode */
  ESP_ERROR_CHECK(esp_wifi_set_mode(WIFI_MODE_STA));
  ESP_ERROR_CHECK(esp_wifi_start());
}

static void get_device_service_name(char *service_name, size_t max) {
  uint8_t eth_mac[6];
  const char *ssid_prefix = "agk radio:";
  esp_wifi_get_mac(WIFI_IF_STA, eth_mac);
  snprintf(service_name, max, "%s%02X%02X%02X", ssid_prefix, eth_mac[3],
           eth_mac[4], eth_mac[5]);
}

#include "esp_timer.h" // Added for watchdog timer

/**
 * @brief Task to measure and log the data throughput in kbps.
 */
static void data_throughput_task(void *pvParameters) {
#define BITRATE_HISTORY_SIZE 10
  static int bitrate_history[BITRATE_HISTORY_SIZE] = {0};
  static int history_index = 0;
  static int consecutive_zero_count = 0;

  uint64_t last_bytes_read = 0;
  uint64_t current_bytes_read;
  uint64_t bytes_read_in_interval;

  static uint64_t prev_idle_0 = 0;
  static uint64_t prev_idle_1 = 0;
  static uint64_t prev_total = 0;

  while (1) {
    vTaskDelay(pdMS_TO_TICKS(BITRATE_UPDATE_INTERVAL_MS));

    current_bytes_read = g_bytes_read;
    bytes_read_in_interval = current_bytes_read - last_bytes_read;
    last_bytes_read = current_bytes_read;

    // Calculate current bitrate and add to history
    int current_bitrate =
        (bytes_read_in_interval * 8) / BITRATE_UPDATE_INTERVAL_MS;
    bitrate_history[history_index] = current_bitrate;
    history_index = (history_index + 1) % BITRATE_HISTORY_SIZE;

    // Calculate weighted moving average
    long weighted_sum = 0;
    int total_weight = 0;
    for (int i = 0; i < BITRATE_HISTORY_SIZE; i++) {
      int weight = i + 1; // Simple linear weight (1 for oldest, 10 for newest)
      int data_index = (history_index + i) % BITRATE_HISTORY_SIZE;
      weighted_sum += bitrate_history[data_index] * weight;
      total_weight += weight;
    }

    g_bitrate_kbps = weighted_sum / total_weight;
    update_bitrate_label(g_bitrate_kbps);

    if (g_enable_sys_monitor) {
      // monitoring ram usage.  remove this for production
      size_t total_ram = heap_caps_get_total_size(MALLOC_CAP_DEFAULT);
      size_t free_ram = heap_caps_get_free_size(MALLOC_CAP_DEFAULT);
      size_t used_ram = total_ram - free_ram;

      // Log RAM usage
      ESP_LOGI(TAG, "RAM: Used: %zu, Free: %zu, Total: %zu", used_ram, free_ram,
               total_ram);
    }

    if (g_enable_sys_monitor) {
      // Core Load Monitoring
      TaskStatus_t status;
      vTaskGetInfo(xTaskGetIdleTaskHandleForCPU(0), &status, pdFALSE, eInvalid);
      uint64_t idle_0 = status.ulRunTimeCounter;

      vTaskGetInfo(xTaskGetIdleTaskHandleForCPU(1), &status, pdFALSE, eInvalid);
      uint64_t idle_1 = status.ulRunTimeCounter;

      uint64_t current_total_time = esp_timer_get_time();

      if (prev_total > 0) {
        uint64_t total_diff = current_total_time - prev_total;
        uint64_t idle_0_diff = idle_0 - prev_idle_0;
        uint64_t idle_1_diff = idle_1 - prev_idle_1;

        // Ensure we don't divide by zero or get negative load due to
        // overflow/timing glitches
        if (total_diff > 0) {
          float load_0 = 100.0f * (1.0f - ((float)idle_0_diff / total_diff));
          float load_1 = 100.0f * (1.0f - ((float)idle_1_diff / total_diff));

          // Clamp to 0-100 range
          if (load_0 < 0)
            load_0 = 0;
          else if (load_0 > 100)
            load_0 = 100;
          if (load_1 < 0)
            load_1 = 0;
          else if (load_1 > 100)
            load_1 = 100;

          ESP_LOGI(TAG, "Core Load: Core 0: %.2f%%, Core 1: %.2f%%", load_0,
                   load_1);
        }
      }

      prev_idle_0 = idle_0;
      prev_idle_1 = idle_1;
      prev_total = current_total_time;
    }

    // Watchdog check
    if (current_bitrate == 0) {
      consecutive_zero_count++;
    } else {
      consecutive_zero_count = 0;
    }

    if (consecutive_zero_count >= 30) {
      ESP_LOGE(TAG, "Watchdog triggered: 0 kbps for 30 consecutive seconds. "
                    "Restarting...");
      esp_restart();
    }
  }
}

void app_main(void) {
  int initial_volume = INITIAL_VOLUME;
  int unmuted_volume = INITIAL_VOLUME;
  bool initial_mute = false;
  esp_log_level_set("*", ESP_LOG_DEBUG);
  // esp_log_level_set(TAG, ESP_LOG_DEBUG);
  // esp_log_level_set("HTTP_STREAM", ESP_LOG_DEBUG);
  esp_err_t err = nvs_flash_init();
  if (err == ESP_ERR_NVS_NO_FREE_PAGES ||
      err == ESP_ERR_NVS_NEW_VERSION_FOUND) {
    ESP_ERROR_CHECK(nvs_flash_erase());
    err = nvs_flash_init();
  }
  ESP_ERROR_CHECK(err);

  init_station_data();

  nvs_handle_t nvs_handle;
  err = nvs_open("storage", NVS_READWRITE, &nvs_handle);
  if (err != ESP_OK) {
    ESP_LOGE(TAG, "Error (%s) opening NVS handle!", esp_err_to_name(err));
  } else {
    ESP_LOGI(TAG, "Reading current_station from NVS");
    int32_t station_from_nvs = 0; // default to 0
    err = nvs_get_i32(nvs_handle, "station_idx", &station_from_nvs);
    switch (err) {
    case ESP_OK:
      ESP_LOGI(TAG, "Successfully read current_station = %d",
               (int)station_from_nvs);
      if (station_from_nvs >= 0 && station_from_nvs < station_count) {
        current_station = station_from_nvs;
      } else {
        ESP_LOGW(TAG, "Invalid station index %d found in NVS, defaulting to 0",
                 (int)station_from_nvs);
        current_station = 0;
      }
      break;
    case ESP_ERR_NVS_NOT_FOUND:
      ESP_LOGI(TAG, "The value 'station_idx' is not initialized yet!");
      break;
    default:
      ESP_LOGE(TAG, "Error (%s) reading!", esp_err_to_name(err));
    }

    // Read volume from NVS
    ESP_LOGI(TAG, "Reading volume from NVS");
    int32_t volume_from_nvs = INITIAL_VOLUME;
    err = nvs_get_i32(nvs_handle, "volume", &volume_from_nvs);
    switch (err) {
    case ESP_OK:
      ESP_LOGI(TAG, "Successfully read volume = %d", (int)volume_from_nvs);
      if (volume_from_nvs >= 0 && volume_from_nvs <= 100) {
        initial_volume = volume_from_nvs;
      } else {
        ESP_LOGW(TAG, "Invalid volume %d found in NVS, defaulting to %d",
                 (int)volume_from_nvs, INITIAL_VOLUME);
      }
      break;
    case ESP_ERR_NVS_NOT_FOUND:
      ESP_LOGI(TAG, "The value 'volume' is not initialized yet!");
      break;
    default:
      ESP_LOGE(TAG, "Error (%s) reading 'volume'!", esp_err_to_name(err));
    }

    // Read mute state from NVS
    ESP_LOGI(TAG, "Reading mute state from NVS");
    uint8_t mute_from_nvs = 0; // default to unmuted
    err = nvs_get_u8(nvs_handle, "mute_state", &mute_from_nvs);
    if (err == ESP_OK) {
      initial_mute = (mute_from_nvs != 0);
      ESP_LOGI(TAG, "Successfully read mute_state = %d", (int)initial_mute);
    } else if (err == ESP_ERR_NVS_NOT_FOUND) {
      ESP_LOGI(TAG, "The value 'mute_state' is not initialized yet!");
    } else {
      ESP_LOGE(TAG, "Error (%s) reading 'mute_state'!", esp_err_to_name(err));
    }

    unmuted_volume = initial_volume;
    if (initial_mute) {
      initial_volume = 0;
    }

    nvs_close(nvs_handle);
  }
#if (ESP_IDF_VERSION >= ESP_IDF_VERSION_VAL(4, 1, 0))
  ESP_ERROR_CHECK(esp_netif_init());
#else
  tcpip_adapter_init();
#endif
  // Create the UI message queue before any UI tasks are started
  g_ui_queue = xQueueCreate(10, sizeof(ui_update_message_t));

  display = lvgl_ssd1306_setup();
  screens_init(display);
  update_station_name(radio_stations[current_station].call_sign);
  update_station_origin(radio_stations[current_station].origin);

  // start oled display test task,  remove after debugging
  // xTaskCreate(task_test_ssd1306, "u8g2_task", 4096, NULL, 5, NULL);

  wifi_event_group = xEventGroupCreate();

  ESP_ERROR_CHECK(esp_event_loop_create_default());
  ESP_ERROR_CHECK(esp_event_handler_register(WIFI_PROV_EVENT, ESP_EVENT_ANY_ID,
                                             &event_handler, NULL));
  ESP_ERROR_CHECK(esp_event_handler_register(WIFI_EVENT, ESP_EVENT_ANY_ID,
                                             &event_handler, NULL));
  ESP_ERROR_CHECK(esp_event_handler_register(IP_EVENT, IP_EVENT_STA_GOT_IP,
                                             &event_handler, NULL));

  esp_netif_create_default_wifi_sta();

  wifi_init_config_t cfg = WIFI_INIT_CONFIG_DEFAULT();
  ESP_ERROR_CHECK(esp_wifi_init(&cfg));

  wifi_prov_mgr_config_t config = {
      .scheme = wifi_prov_scheme_ble,
      .scheme_event_handler = WIFI_PROV_SCHEME_BLE_EVENT_HANDLER_FREE_BTDM};

  ESP_ERROR_CHECK(wifi_prov_mgr_init(config));

  // Check for forced provisioning (Volume button held during boot)
  init_encoder_switches();
  if (is_volume_switch_pressed()) {
    ESP_LOGI(TAG, "Volume button held at boot - Forcing Reprovisioning!");
    wifi_prov_mgr_reset_provisioning();
  }

  bool provisioned = false;
  ESP_ERROR_CHECK(wifi_prov_mgr_is_provisioned(&provisioned));
  // provisioned = false; // force provisioning for testing comment this line
  // for production
  uint8_t custom_service_uuid[] = {
      /* LSB <---------------------------------------
       * ---------------------------------------> MSB */
      0xb4, 0xdf, 0x5a, 0x1c, 0x3f, 0x6b, 0xf4, 0xbf,
      0xea, 0x4a, 0x82, 0x03, 0x04, 0x90, 0x1a, 0x02,
  };

  if (!provisioned) {
    ESP_LOGI(TAG, "Starting provisioning");

    char service_name[20];
    get_device_service_name(service_name, sizeof(service_name));

    wifi_prov_scheme_ble_set_service_uuid(custom_service_uuid);
    ESP_ERROR_CHECK(wifi_prov_mgr_start_provisioning(WIFI_PROV_SECURITY_1, NULL,
                                                     service_name, NULL));
  } else {
    ESP_LOGI(TAG, "Already provisioned, starting Wi-Fi");
  }

  ESP_LOGI(TAG, "Waiting for Wi-Fi connection...");
  wifi_init_sta();
  xEventGroupWaitBits(wifi_event_group, WIFI_CONNECTED_BIT, false, true,
                      portMAX_DELAY);
  ESP_LOGI(TAG, "Wi-Fi Connected.");
  start_web_server();

  // wifi_event_group = xEventGroupCreate();

  // ESP_ERROR_CHECK(esp_event_loop_create_default());
  // ESP_ERROR_CHECK(esp_event_handler_register(WIFI_PROV_EVENT,
  // ESP_EVENT_ANY_ID, &event_handler, NULL));
  // ESP_ERROR_CHECK(esp_event_handler_register(WIFI_EVENT, ESP_EVENT_ANY_ID,
  // &event_handler, NULL));
  // ESP_ERROR_CHECK(esp_event_handler_register(IP_EVENT, IP_EVENT_STA_GOT_IP,
  // &event_handler, NULL));

  // esp_netif_create_default_wifi_sta();

  // wifi_init_config_t cfg = WIFI_INIT_CONFIG_DEFAULT();
  // ESP_ERROR_CHECK(esp_wifi_init(&cfg));

  // wifi_prov_mgr_config_t config = {
  //     .scheme = wifi_prov_scheme_ble,
  //     .scheme_event_handler = WIFI_PROV_SCHEME_BLE_EVENT_HANDLER_FREE_BTDM
  // };

  // ESP_ERROR_CHECK(wifi_prov_mgr_init(config));

  // bool provisioned = false;
  // ESP_ERROR_CHECK(wifi_prov_mgr_is_provisioned(&provisioned));
  // provisioned = false; // force provisioning for testing comment this line
  // for production uint8_t custom_service_uuid[] = {
  //     /* LSB <---------------------------------------
  //      * ---------------------------------------> MSB */
  //     0xb4, 0xdf, 0x5a, 0x1c, 0x3f, 0x6b, 0xf4, 0xbf,
  //     0xea, 0x4a, 0x82, 0x03, 0x04, 0x90, 0x1a, 0x02,
  // };

  // if (!provisioned) {
  //     ESP_LOGI(TAG, "Starting provisioning");

  //     char service_name[20];
  //     get_device_service_name(service_name, sizeof(service_name));

  //     wifi_prov_scheme_ble_set_service_uuid(custom_service_uuid);
  //     ESP_ERROR_CHECK(wifi_prov_mgr_start_provisioning(WIFI_PROV_SECURITY_1,
  //     NULL, service_name, NULL));
  // }
  // else {
  //     ESP_LOGI(TAG, "Already provisioned, starting Wi-Fi");
  //     wifi_prov_mgr_deinit();

  //     ESP_ERROR_CHECK(esp_event_handler_register(WIFI_EVENT,
  //     ESP_EVENT_ANY_ID, &event_handler, NULL));
  //     /* Start Wi-Fi station */
  //     wifi_init_sta();

  // }

  // const TickType_t wifi_connect_timeout = portMAX_DELAY; //
  // pdMS_TO_TICKS(30000); // 30 seconds ESP_LOGI(TAG, "Waiting for Wi-Fi
  // connection..."); we should probably have a timeout here.  If it can't
  // connect, restart provisioning. EventBits_t bits =
  // xEventGroupWaitBits(wifi_event_group, WIFI_CONNECTED_BIT, pdFALSE, pdTRUE,
  // wifi_connect_timeout);

  // if ((bits & WIFI_CONNECTED_BIT) == 0) {
  //     ESP_LOGE(TAG, "Failed to connect to Wi-Fi within 30 seconds. Resetting
  //     provisioning and restarting.");
  //     // Erase provisioning data
  //     wifi_prov_mgr_reset_provisioning();
  //     vTaskDelay(pdMS_TO_TICKS(2000)); // Delay to allow logging
  //     esp_restart();
  // }

  ESP_LOGI(TAG, "Wi-Fi Connected.");

  esp_periph_config_t periph_cfg = DEFAULT_ESP_PERIPH_SET_CONFIG();
  periph_set = esp_periph_set_init(&periph_cfg);

  ESP_LOGI(TAG, "Start audio codec chip");
  board_handle = audio_board_init(); // Assign to global
  // explicit start the codec, I'm not sure why it was not started elsewhere.
  board_handle->audio_hal->audio_codec_ctrl(AUDIO_HAL_CODEC_MODE_BOTH,
                                            AUDIO_HAL_CTRL_START);
  audio_hal_set_volume(board_handle->audio_hal, initial_volume);
  update_volume_slider(initial_volume);
  // audio_hal_get_volume(board_handle->audio_hal, &temp_volume);
  // ESP_LOGI(TAG, "Initial volume set to %d", temp_volume);

  ESP_LOGI(TAG, "Set up  event listener");
  audio_event_iface_cfg_t evt_cfg = AUDIO_EVENT_IFACE_DEFAULT_CFG();
  evt = audio_event_iface_init(&evt_cfg); // Assign to static global

  ESP_LOGI(TAG, "Listening event from peripherals");
  audio_event_iface_set_listener(esp_periph_set_get_event_iface(periph_set),
                                 evt);

  ESP_LOGI(TAG, "Initializing IR RMT");
  g_ir_tx_channel = init_ir_rmt(IR_TX_GPIO_NUM);
  ESP_LOGI(TAG, "Sending Bose AUX signal");
  send_bose_ir_command(g_ir_tx_channel, BOSE_CMD_AUX);

  ESP_LOGI(TAG, "Starting initial stream: %s, %s",
           radio_stations[current_station].call_sign,
           radio_stations[current_station].origin);
  err = create_audio_pipeline(&audio_pipeline_components,
                              radio_stations[current_station].codec,
                              radio_stations[current_station].uri);
  if (err != ESP_OK) {
    ESP_LOGE(TAG, "Failed to create initial audio pipeline, error: %d", err);
    // Cleanup before returning
    if (evt)
      audio_event_iface_destroy(evt);
    if (periph_set)
      esp_periph_set_destroy(periph_set);
    // audio_board_deinit(board_handle); // If applicable
    return;
  }

  ESP_LOGI(TAG, "Start audio_pipeline");
  audio_pipeline_run(audio_pipeline_components.pipeline);

  xTaskCreate(data_throughput_task, "data_throughput_task", 3 * 1024, NULL, 5,
              NULL);

  //  start encoder pulse counters

  init_encoders(board_handle, initial_volume, initial_mute, unmuted_volume);

  while (1) {
    audio_event_iface_msg_t msg;
    esp_err_t ret = audio_event_iface_listen(evt, &msg, portMAX_DELAY);
    if (ret != ESP_OK) {
      ESP_LOGE(TAG, "[ * ] Event interface error : %d", ret);
      continue;
    }
    ESP_LOGI(TAG, "Received event from element: %X, command: %d",
             (int)msg.source, msg.cmd);
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

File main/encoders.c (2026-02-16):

/*
 * SPDX-FileCopyrightText: 2010-2022 Espressif Systems (Shanghai) CO LTD
 *
 * SPDX-License-Identifier: CC0-1.0
 */

#include "encoders.h"
//  #include "sdkconfig.h"
#include "driver/gpio.h"
#include "driver/pulse_cnt.h"
#include "esp_log.h"
// #include "freertos/FreeRTOS.h"
#include "freertos/queue.h"
#include "freertos/task.h"

#include "audio_hal.h"
// #include "esp_sleep.h"
#include "nvs_flash.h" // this is needed even though linter suggests otherwise
#include <limits.h>

#include "board.h"
#include "esp_netif.h"
#include "esp_timer.h"
#include "internet_radio_adf.h"
#include "ir_rmt.h"
#include "screens.h"
#include "station_data.h"
#include <inttypes.h>

static const char *TAG = "encoders";

// extern audio_board_handle_t board_handle;

extern int station_count;
extern int current_station;
extern rmt_channel_handle_t g_ir_tx_channel;

#define VOLUME_GPIO_A 42
#define VOLUME_GPIO_B 2
#define VOLUME_PRESS_GPIO 1

#define STATION_GPIO_A 39
#define STATION_GPIO_B 40
#define STATION_PRESS_GPIO 41

// polling periods
#define VOLUME_POLLING_PERIOD_MS 100
#define VOLUME_PRESS_POLLING_PERIOD_MS 20

#define STATION_POLLING_PERIOD_MS 100
#define STATION_PRESS_POLLING_PERIOD_MS 100

// this pause allows the user to change the station multiple times before the
// change takes effect
#define DELAY_BEFORE_STATION_CHANGE_MS 2000
// timing for long press on station switch to reboot
#define LONG_PRESS_TIME_MS 1500
// time to display IP address on screen
#define IP_SCREEN_DISPLAY_TIME_MS 3000
// reboot message is displayed for this time before rebooting
#define REBOOT_MESSAGE_DISPLAY_TIME_MS 100
// Time window to detect a second click for double-click actions
#define DOUBLE_CLICK_TIMEOUT_MS 300

typedef struct {
  pcnt_unit_handle_t pcnt_unit;
  int speed;
  int value;
  int adjust;
  audio_board_handle_t board_handle;
} limited_pulse_counter_t;

typedef struct {
  pcnt_unit_handle_t pcnt_unit;
  int current_index;
  const int *values;
  int num_values;
} cyclic_pulse_counter_t;
static cyclic_pulse_counter_t *g_station_counter_ptr = NULL;

// Mute functionality state
static bool is_muted = false;
static int volume_before_mute = 0;
static limited_pulse_counter_t *g_volume_counter_ptr =
    NULL; // Pointer to the volume counter for shared access

static void save_volume_to_nvs(int volume) {
  nvs_handle_t nvs_handle;
  esp_err_t err = nvs_open("storage", NVS_READWRITE, &nvs_handle);
  if (err != ESP_OK) {
    ESP_LOGE(TAG, "Error (%s) opening NVS handle for writing volume!",
             esp_err_to_name(err));
    return;
  }

  err = nvs_set_i32(nvs_handle, "volume", volume);
  if (err != ESP_OK) {
    ESP_LOGE(TAG, "Error (%s) writing 'volume' to NVS!", esp_err_to_name(err));
  } else {
    ESP_LOGD(TAG, "Saved volume = %d to NVS", volume);
  }

  err = nvs_commit(nvs_handle);
  if (err != ESP_OK) {
    ESP_LOGE(TAG, "Error (%s) committing 'volume' to NVS!",
             esp_err_to_name(err));
  }

  nvs_close(nvs_handle);
}

static void save_mute_state_to_nvs(bool muted) {
  nvs_handle_t nvs_handle;
  esp_err_t err = nvs_open("storage", NVS_READWRITE, &nvs_handle);
  if (err != ESP_OK) {
    ESP_LOGE(TAG, "Error (%s) opening NVS handle for writing mute state!",
             esp_err_to_name(err));
    return;
  }

  err = nvs_set_u8(nvs_handle, "mute_state", muted ? 1 : 0);
  if (err != ESP_OK) {
    ESP_LOGE(TAG, "Error (%s) writing 'mute_state' to NVS!",
             esp_err_to_name(err));
  } else {
    ESP_LOGD(TAG, "Saved mute_state = %d to NVS", muted);
  }

  err = nvs_commit(nvs_handle);
  if (err != ESP_OK) {
    ESP_LOGE(TAG, "Error (%s) committing 'mute_state' to NVS!",
             esp_err_to_name(err));
  }

  nvs_close(nvs_handle);
}

// update the volume by clamping to range 0-100.  The adjust parameter is used
// to adapt the current pulse count to the clamped volume.  In this way one can
// adjust well below 0 but after ajustment it only take a click to get back
// above 0.
void update_volume_pulse_counter(void *pvParameters) {
  limited_pulse_counter_t *counter = (limited_pulse_counter_t *)pvParameters;
  g_volume_counter_ptr = counter; // Store pointer for global access

  // Restore initial volume to PCNT counter state
  // The counter is at 0, so we need to adjust it to match the initial volume
  int initial_count_offset =
      (counter->value - counter->adjust) * 4 / counter->speed;
  pcnt_unit_clear_count(counter->pcnt_unit);
  // This is a bit of a hack to set the counter. There's no direct 'set_count'
  if (initial_count_offset != 0) {
    // We can't directly set the count, but we can adjust our 'adjust' value
    // so that the next calculation is correct.
    // The formula is: new_volume = count / 4 * speed + adjust
    // We want new_volume to be initial_volume when count is 0.
    counter->adjust = counter->value;
  }

  for (;;) {
    int count;
    ESP_ERROR_CHECK(pcnt_unit_get_count(counter->pcnt_unit, &count));
    int new_volume = count / 4 * counter->speed + counter->adjust;
    if (new_volume < 0) {
      counter->adjust = -count / 4 * counter->speed;
      new_volume = 0;
    } else if (new_volume > 100) {
      counter->adjust = 100 - count / 4 * counter->speed;
      new_volume = 100;
    }
    if (new_volume != counter->value) {
      // If muted and user changes volume, unmute first
      if (is_muted) {
        // Calculate the 'delta' applied by the encoder
        int delta = new_volume - counter->value;
        // Restore based on previous volume plus the delta
        new_volume = volume_before_mute + delta;

        // Clamp restored volume to 0-100 range
        if (new_volume < 0) {
          new_volume = 0;
        } else if (new_volume > 100) {
          new_volume = 100;
        }

        // Correct the adjust value so that future 'new_volume' calculations
        // from the hardware counter match this restored volume.
        counter->adjust = new_volume - (count / 4 * counter->speed);

        is_muted = false;
        ESP_LOGI(TAG, "Unmuted by volume change to %d (restored from %d)",
                 new_volume, volume_before_mute);
        save_mute_state_to_nvs(false);
      }

      counter->value = new_volume;
      ESP_LOGI(TAG, "Setting volume to: %d", new_volume);
      audio_hal_set_volume(counter->board_handle->audio_hal, new_volume);
      update_volume_slider(new_volume);
      save_volume_to_nvs(new_volume);
    }

    vTaskDelay(
        pdMS_TO_TICKS(VOLUME_POLLING_PERIOD_MS)); // Poll for volume changes
  }
}
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

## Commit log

2025-05-23 Initial commit of internet radio based on esp-adf example pipeline_living_stream
    [partitions_internet_radio_adf.csv]
2025-05-25 Added volume buttons but we are losing I2C connection. The original code: living_stream did not lose I2C.
2025-06-07 Moved code to set sample rate/sample depth/channels from the event handler to a callback assigned to the codec
2025-06-09 Added new statiions and identified part of button code that fails
    [internet_radio_adf.c]
2025-07-11 created station up and station down buttons and removed the volume buttons. Added lcd 1602 code but it doesn't work.
2025-07-11 Added station up and station down buttons, removed volume.
2025-07-15 Start lcd 16x2 after es8388 to allow streaming, though there are still i2c errors and it won't update after a while.
    [internet_radio_adf.c]
2025-07-18 Working version prior to forking lyrat board to a custom board.
2025-07-18 Return to lyrat board
2025-08-14 Complete transition to zorxx lcd 1602 driver
2025-09-04 remove earlier lcd1602 i2c library and other cleanups
2025-09-04 Solved LCD1602 reliablity problem by putting the LCD task on core 0 to avoid simulaneous execution with wifi
    [internet_radio_adf.c]
2025-09-04 Add flac support. Doesn't work at the moment.
    [internet_radio_adf.c]
2025-09-05 replace placeholder lcd code with code to write call sign and city.
    [internet_radio_adf.c]
2025-09-05 Moved current_station to nvs storage so that the station is preserved across boots.
2025-10-23 Added a couple of stations and tried aac+ without success.
2025-10-23 update to esp32 S3, remove lcd 1602 support
2025-10-24 Set up wifi provisioning. include ADF components with PRIV REQUIRES. Removed some V1 cruft. Provisioning advertising works but subsequent connection is not working.
    [internet_radio_adf.c]
2025-10-27 Add a timeout on wifi connection so that a failed attempt to connect erases saved wifi credentials and triggers a reprovision event. This will allow us to connect to a different network (while losing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
    [internet_radio_adf.c]
2025-10-28 Custom board compiles now with much hackery. We can now start debugging connection to es8388
2025-10-28 revert to earlier prvisioning using ble without the ability to reprovision.
    [internet_radio_adf.c]
2025-10-31 Fixed i2s dout/din confusion: dout on esp32 -> din on es8388. Explicitly started the es8388 codec. This version streams audio.
    [internet_radio_adf.c]
2025-10-31 Added oled 128x64 panel. refactored es8388 to keep makelist.txt inside directory. updated u8g2 to modern i2c driver.
2025-11-12 Replaced u8g2 with lvgl. Created a display initialization file and a screen creation file.
    [internet_radio_adf.c, lvgl_ssd1306_setup.c]
2025-11-13 Attached rotary encoder to volume on audio board and on UI. Volume is saved in NVS. There are still some NACK issues but it works pretty well.
    [encoders.c, internet_radio_adf.c]
2025-11-13 Arranged for initial volume from nvs to be used to initialize the volume encoder.
2025-11-13 Add volume encoder pushbutton as a mute button. The audio is unmuted with either another press or volume adjustment.
2025-11-14 Connected rotary encoder to station select cyclic counter using the same hardware for testing. The station select screen and actions have not been added yet.
2025-11-14 Initialize station selector item count and current value from globals.
2025-11-14 Add a station select screen. Multiple problems: updating home screen while station select screen is active gives core dump, clicks of encoder do not correspond with roller movements in a 1:1 manner, 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
    Still to be done: connect station change events to pipeline, store new station in nvs, move back and forth between the two screens.
    [encoders.c, internet_radio_adf.c, station_data.c]
2025-11-14 Fixed core dumps, arranged for the station select screen to show when moving station select encoder, change stations when paused, and return to home screen.
    Removed old pushbutton interface for station selection as that is no longer needed.
    [encoders.c, internet_radio_adf.c]
2025-11-15 Enabled both encoders, changed direction on station select (there may be some A/B wiring issues still), added gnomon to station select roller, added restart to station select pushbutton. All seems to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
    Still to work on
    * more responsive ui
    * watchdog timer is triggered sometimes
    [encoders.c, internet_radio_adf.c]
2025-11-16 Return to esp idf 5.5.1 from 6.0 for more stability. Also deleted some unused code.
    [internet_radio_adf.c]
2025-11-16 reduced max period between lvgl updates from 500ms to 100ms to get a more responsive ui. Keep an eye out for watchdog timer.
2025-11-17 Made bitrate sampling period controlable by macro. Set to 2 seconds. This helped identify feed issues with one station.
    [internet_radio_adf.c]
2025-11-17 Added weighted (lineary weights) average of last 10 one second bitrates to both smooth the bitrate measurements and also track current network issues.
    [internet_radio_adf.c]
2025-11-20 Removed some testing code. Started tracking http errors for possible restart actions.
    [internet_radio_adf.c]
2025-11-29 Added IR remote. We can send on/off or aux signals to bose wave radio. on/off is stateful so its effect depends on the current state of the radio. It is safer to send aux since it is idempotent. aux 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
    Currently we send aux during boot time to ensure that the bose radio is on before the audio pipeline is started.
2025-11-30 Added two buttons for controlling bose radio on/off. One button sends the aux signal which turns the radio on if it is not currently on. The other button send the aux signal to ensure that the radio 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
2025-11-30 Undefined the gpio used for adaptive audio on the audio board. This allows us to use the gpio for sending ir_rmt commands. Move the init of these pin earlier so that we can check for button down on b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
2025-11-30 Trigger a reprovisioning event by holding down bose_on_off button at boot time. I still need to add a messages screen to tell the user that we are waiting for provisioning.
2025-12-01 Added an information screen when the radio is waiting for wifi provisioning. Tried to use italic but it didn't weem to work.
    [internet_radio_adf.c]
2025-12-02 Added schematic.
    [schematic.kicad_pcb, schematic.kicad_sch]
2025-12-09 refactor: Adjust OLED symbol layout, pin positions, and associated labels in schematic.
    [schematic.kicad_sch]
2025-12-09 fix: Ensure audio pipeline and peripheral cleanup always executes after the main loop.
    [internet_radio_adf.c]
2025-12-09 feat: add watchdog to restart device if no data throughput is detected after a typical startup duration.
2025-12-10 feat: long press on station select button will trigger reboot after being held for 3 s. Previous implementation waited for the button to be released to determine if a click was long or short.
    [encoders.c]
2025-12-10 feat: Add reboot screen and configurable timings for long-press reboot and IP display.
    [encoders.c]
2025-12-14 Added schematics to the build details.
2025-12-14 Adjust schematic path.
2025-12-15 Add load measurements for the two cores. Note: this changes config outside of menuconfig so it might have created some problems for esp-idf. Also we might want to remove this for production.
    [internet_radio_adf.c]
2025-12-16 Add a double click action to the volume button to send the on/off toggle over the ir remote. This will allow us to remove the two on/off buttons in the design. The idea is that on boot time an idempo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
    It would be nice to find a way to send an off signal during the brown-out period if possible.
    [encoders.c, internet_radio_adf.c]
2025-12-16 Update schematic with note that the IR remote buttons might not be necessary.
    [schematic.kicad_sch]
2025-12-18 feat: Implement web server for dynamic station management using SPIFFS and a JSON API. * store current station set in spiffs in a json file * expose web app for adding, removing, reording stations.
    [partitions_internet_radio_adf.csv]
2025-12-18 feat: Add and document forced Wi-Fi reprovisioning by holding the station encoder button at boot.
2025-12-18 remove Bose button control logic. bose ir rmt signals are sent at boot time (aux) and with double click on volume switch (on/off).
    Also lengthing double click timeout so that we can doubleclick a bit more slowly.
2025-12-18 Moved the reprovisioning function at boottime to the volume button. This avoids the possiblity that the user holds the reboot (station) button too long and accidentally enters reprovisioning and cons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
    [encoders.c, internet_radio_adf.c]
2025-12-21 Solve AAC+ problem: enable it for aac component, move all codec segments into core 1 for more processing power and increase clock rate from 160MHz to 240MHz
2025-12-29 Move es8388 driver into component so that we can control gain on channel 2 without affecting master esp-adf
2025-12-29 Update documentation with new es8388 driver update
2026-01-20 Remove a station that was skipping.
    [station_data.c]
2026-01-21 added flag `g_enable_sys_monitor` to control the printing of cpu/ram usage on the throughput interval. Disabling this will reduce noise in logs during debugging.
    [internet_radio_adf.c]
2026-01-21 Store the muted state along with unmuted volume to NVS so that when a reboot occurs while the radio is muted it will reboot into a muted state. This will prevent the radio from accidentally "turn on"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
    [encoders.c, internet_radio_adf.c]
2026-01-23 Update unmute from encoder turn: check stored resume volume to resume from that level. Prior to this if the radio rebooted while muted and was unmuted with volume turn, it reverted to volume 0 instea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
    [encoders.c]
2026-01-29 update documentation with header wiring diagram and fuller explanation of encoder functions
2026-01-31 add switch to schematic. added command lines for downloading and uploading json station information.
    [schematic.kicad_sch]
2026-02-05 vendored esp_peripherials. this allows us to freeze esp-idf 5.5.1 and esp-adf 2.8 on esp32-s3. In particular the crc library for bluefi was failing with this combination prior to the fix.
2026-02-16 Increased the size of the stack for the station encoder task. Apparently in idf 5.4.3 more stack is required.
